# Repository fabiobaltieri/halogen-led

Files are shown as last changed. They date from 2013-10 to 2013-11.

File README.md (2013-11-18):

Halogen-LED
==================

http://fabiobaltieri.com/2013/11/18/halogen-led/

This project is an hardware design for an halogen lamp replacement, and it's
designed to run on a legacy low voltage AC halogen power supply.

License
-------

This work is licensed under a Creative Commons Attribution-ShareAlike 3.0
License.

Contents
--------

    README        this file
    docs/         LED datasheets
    hardware/     source directory for the hardware files

Hardware
--------

All hardware files (schematic, layout and libraries) are in CadSoft Eagle
format.

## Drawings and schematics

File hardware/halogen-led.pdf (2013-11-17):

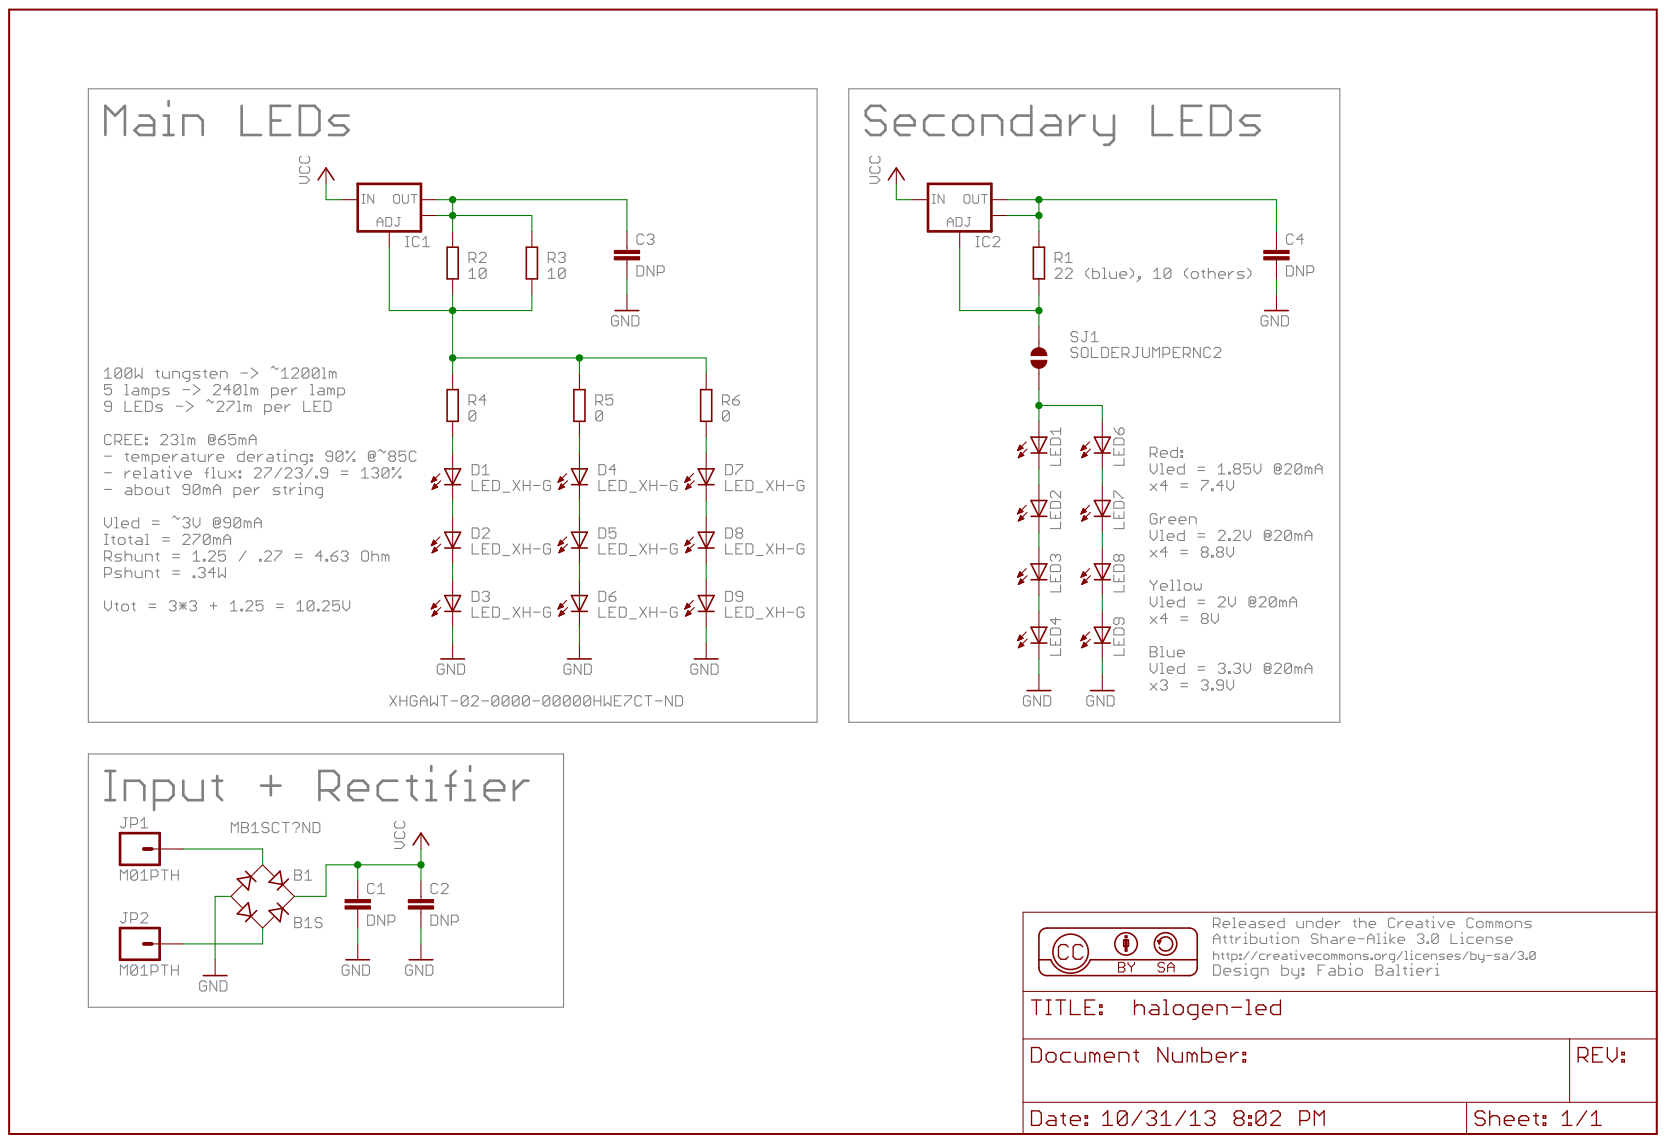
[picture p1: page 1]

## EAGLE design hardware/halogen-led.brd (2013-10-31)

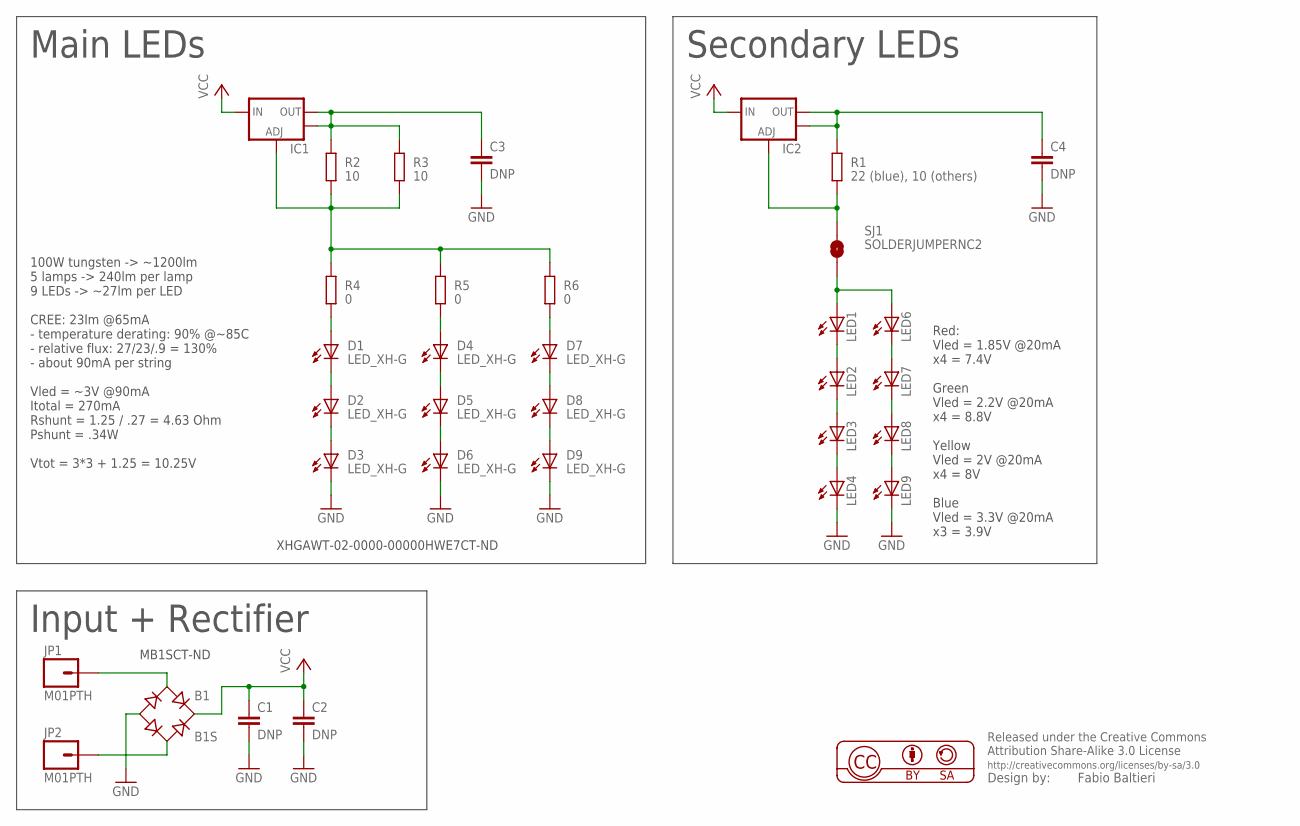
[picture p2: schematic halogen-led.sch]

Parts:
B1: B1S; MBS
C1, C2: DNP; C1206
C3, C4: DNP; C0805
D1, D2, D3, D4, D5, D6, D7, D8, D9: LED_XH-G; CREE_XHG
IC1, IC2: V_REG_LM1117SOT223; SOT223
JP1, JP2: M01PTH; 1X01
LED1, LED2, LED3, LED4, LED6, LED7, LED8, LED9: LEDCHIPLED_0805; CHIPLED_0805
R1: 22 (blue), 10 (others); R1206
R2, R3: 10; R1206
R4, R5, R6: 0; R0805
SJ1: SOLDERJUMPERNC2; SJ_2S-NOTRACE

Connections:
GND: B1.-, C1.2, C2.2, C3.2, C4.2, D3.C, D3.C@1 (C), D6.C, D6.C@1 (C), D9.C, D9.C@1 (C), LED4.C, LED9.C
unnamed: B1.AC2, JP2.1
unnamed: B1.AC1, JP1.1
unnamed: C3.1, IC1.2 (OUT), IC1.4 (OUT), R2.2, R3.2
unnamed: IC1.1 (ADJ), R2.1, R3.1, R4.2, R5.2, R6.2
unnamed: D1.A, D1.A@1 (A), R4.1
unnamed: D4.A, D4.A@1 (A), R5.1
unnamed: LED3.C, LED4.A
unnamed: LED2.C, LED3.A
unnamed: LED1.C, LED2.A
unnamed: LED1.A, LED6.A, SJ1.2
unnamed: D2.C, D2.C@1 (C), D3.A, D3.A@1 (A)
unnamed: D1.C, D1.C@1 (C), D2.A, D2.A@1 (A)
unnamed: D5.C, D5.C@1 (C), D6.A, D6.A@1 (A)
unnamed: D4.C, D4.C@1 (C), D5.A, D5.A@1 (A)
unnamed: D8.C, D8.C@1 (C), D9.A, D9.A@1 (A)
unnamed: C4.1, IC2.2 (OUT), IC2.4 (OUT), R1.2
unnamed: D7.C, D7.C@1 (C), D8.A, D8.A@1 (A)
unnamed: LED8.C, LED9.A
unnamed: LED7.C, LED8.A
unnamed: LED6.C, LED7.A
unnamed: D7.A, D7.A@1 (A), R6.1
unnamed: IC2.1 (ADJ), R1.1, SJ1.1
VCC: B1.+, C1.1, C2.1, IC1.3 (IN), IC2.3 (IN)

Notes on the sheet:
Red: Vled = 1.85V @20mA x4 = 7.4V Green Vled = 2.2V @20mA x4 = 8.8V Yellow Vled = 2V @20mA x4 = 8V Blue Vled = 3.3V @20mA x3 = 3.9V
XHGAWT-02-0000-00000HWE7CT-ND
MB1SCT‑ND
100W tungsten -> ~1200lm 5 lamps -> 240lm per lamp 9 LEDs -> ~27lm per LED CREE: 23lm @65mA - temperature derating: 90% @~85C - relative flux: 27/23/.9 = 130% - about 90mA per string Vled = ~3V @90mA Itotal = 270mA Rshunt = 1.25 / .27 = 4.63 Ohm Pshunt = .34W Vtot = 3*3 + 1.25 = 10.25V
Input + Rectifier
Main LEDs
Secondary LEDs

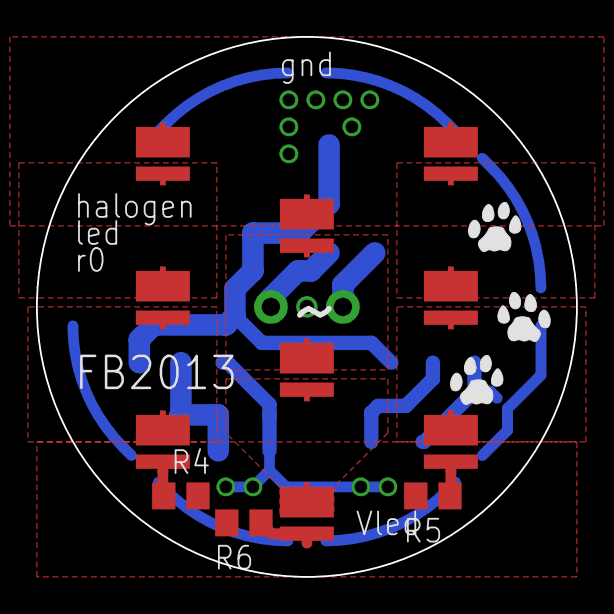
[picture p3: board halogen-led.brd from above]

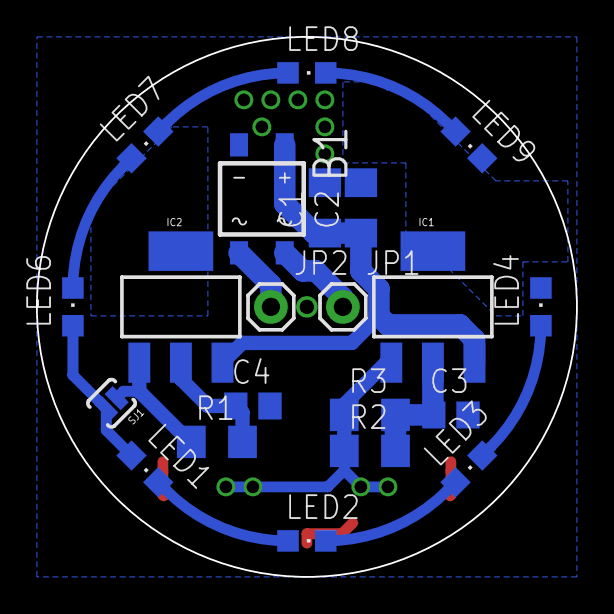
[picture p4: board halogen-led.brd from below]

Board: 2 copper layers, 30.0 x 30.0 mm, 36 parts (21 on the bottom side), 24 nets.

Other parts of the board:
U$1: CAT-R
U$2, U$3: CAT-L

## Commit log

2013-10-31 hw: changed some values
    [halogen-led.brd, halogen-led.sch]
2013-11-17 hw: add pdf schematics

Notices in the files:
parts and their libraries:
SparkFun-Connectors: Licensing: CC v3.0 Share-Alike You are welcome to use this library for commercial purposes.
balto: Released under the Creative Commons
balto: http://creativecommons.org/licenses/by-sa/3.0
